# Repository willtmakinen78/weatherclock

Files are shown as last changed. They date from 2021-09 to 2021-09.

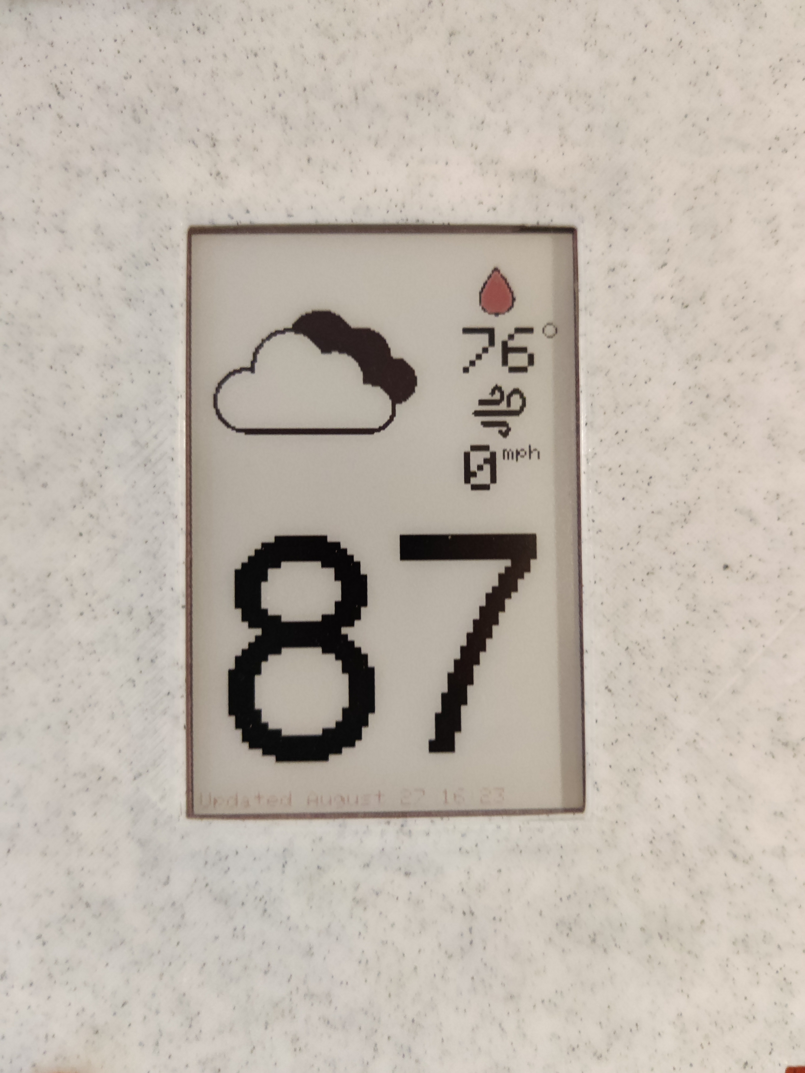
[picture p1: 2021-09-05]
pics/IMG_20210827_170801.jpg

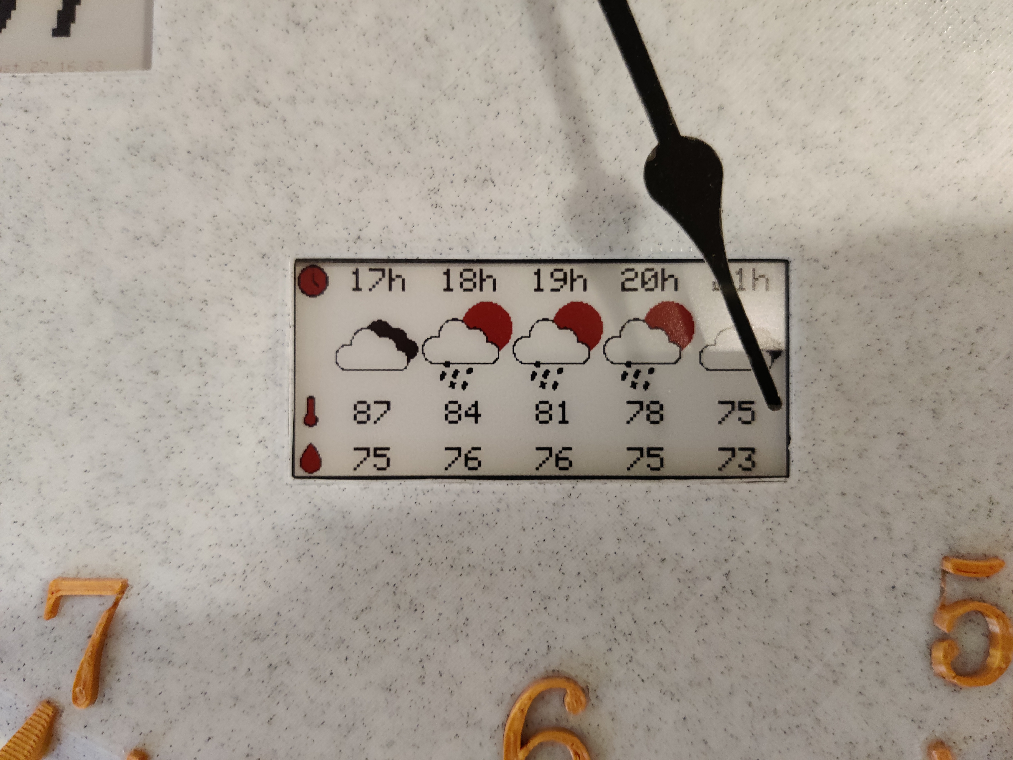
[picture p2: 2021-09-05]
pics/IMG_20210827_170815.jpg

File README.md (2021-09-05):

# weatherclock
An analog-digital hybrid wall clock that can tell the time and give a forecast for the current day.

This was one of my first forways into low power IOT electronics. At its core is an esp32, which is able to be placed into a deep sleep mode and absolutely sip power. Using two e-ink displays, the esp32 wakes up once an hour, grabs the current and hourly forecast from openweathermap.org, updates the displays, and then goes back to sleep. Due to to the fact that e-ink displays consume no power to hold an image on screen, power is only consumed during this update period once an hour, with the esp32 consuming microamps of current during sleep. This allows the clock to have a battery life of about one year, after which it can be charged through the integrated charing port.

Given the limited amount of display space available, the weather paremeters to display were chosen to reflect those most pertinent to running: temperature, dewpoint, and wind. Additionally, in the event of an SD card failure or low battery, one of the screens will be taken up by displaying an error icon notifying the user, as can be seen in the code.

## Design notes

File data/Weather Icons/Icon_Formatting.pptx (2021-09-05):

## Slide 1

11

11

11

11

11

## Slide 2

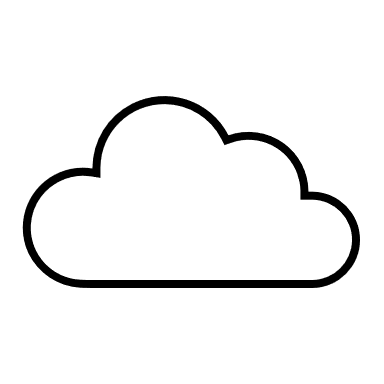
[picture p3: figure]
Cloud

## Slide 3

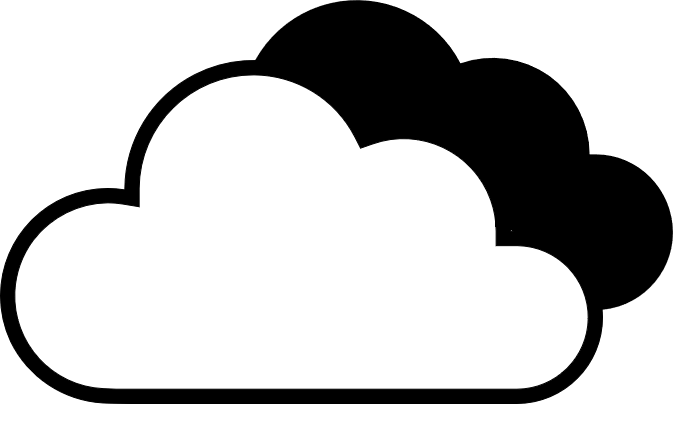
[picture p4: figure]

11

11

11

11

11

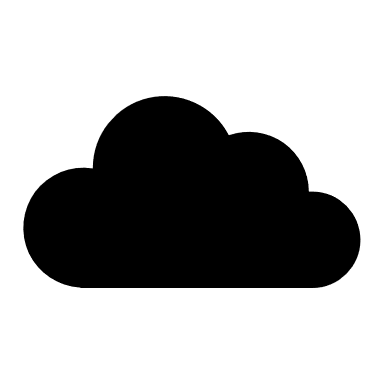
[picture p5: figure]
Cloud

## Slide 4

11

11

11

11

11

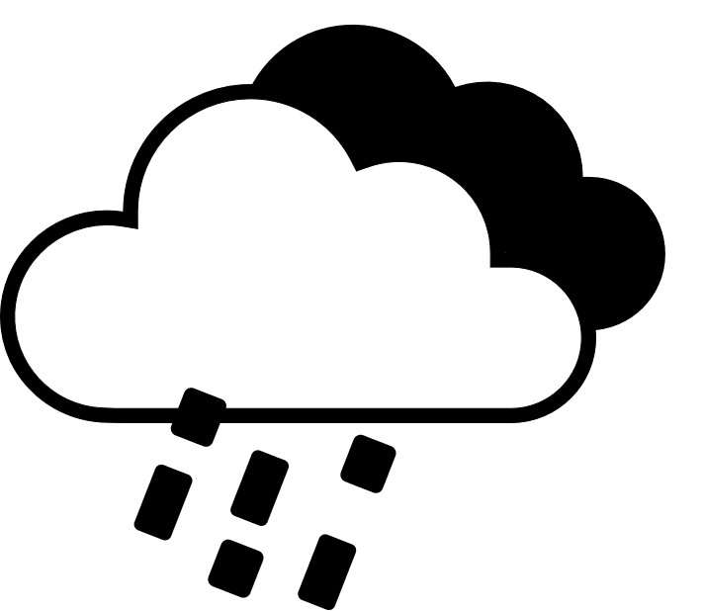
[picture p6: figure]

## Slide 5

11

11

11

11

11

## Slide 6

11

11

11

11

11

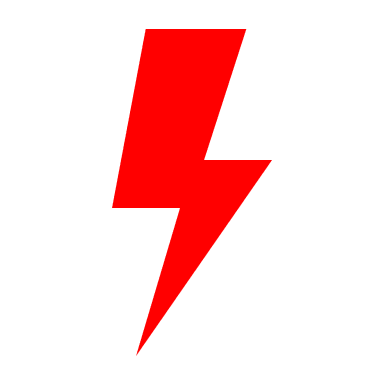
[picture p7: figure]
Lightning bolt
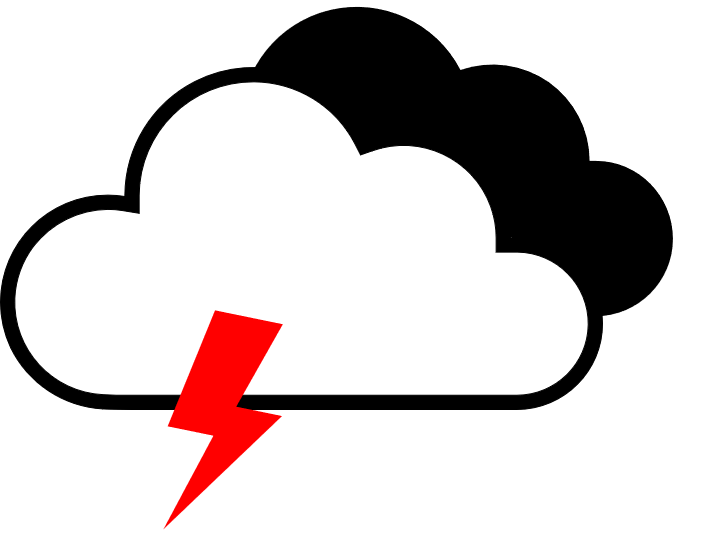
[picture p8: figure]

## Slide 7

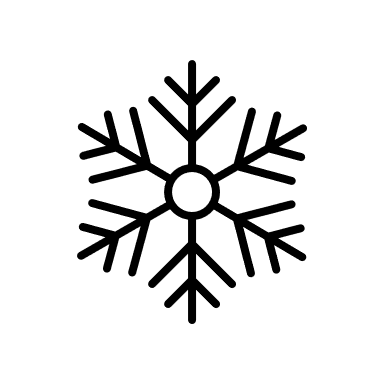
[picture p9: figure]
Snowflake
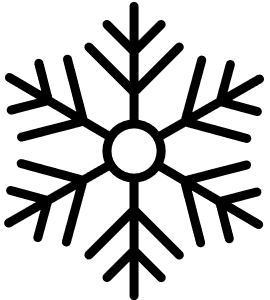
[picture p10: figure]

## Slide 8

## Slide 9

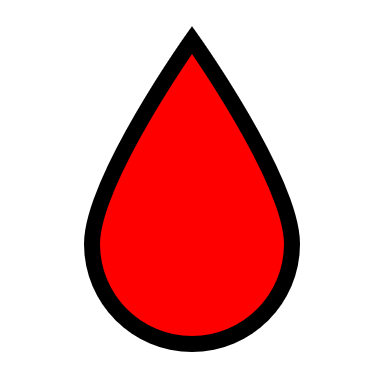
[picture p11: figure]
Water

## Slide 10

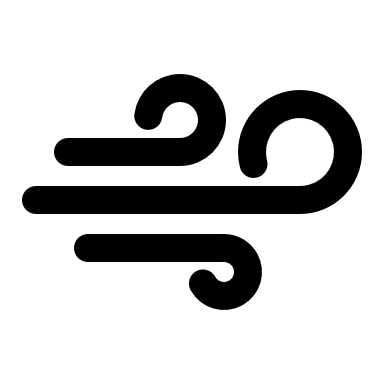
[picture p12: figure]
Windy
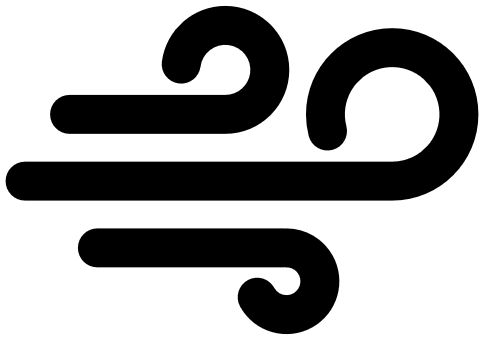
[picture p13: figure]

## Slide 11

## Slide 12

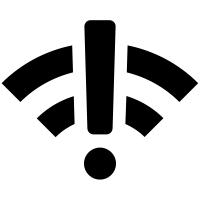
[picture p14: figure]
No Wifi Icons - Download Free Vector Icons | Noun Project
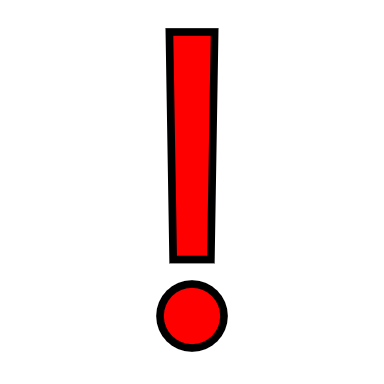
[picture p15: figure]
Exclamation mark
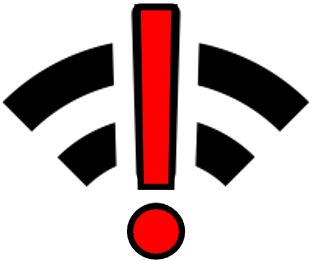
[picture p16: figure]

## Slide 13

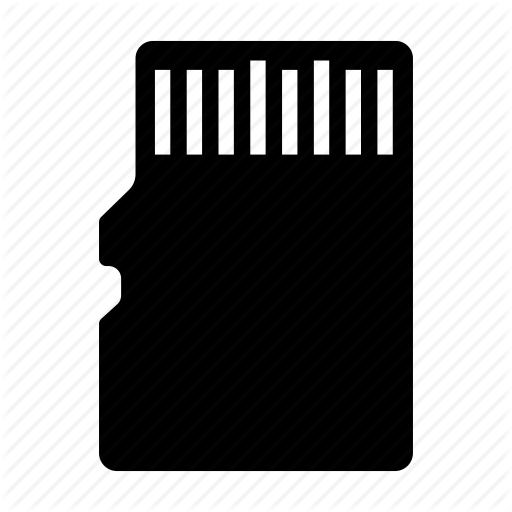
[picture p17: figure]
Data, flash memory, memory, memory card, micro sd, sd card icon
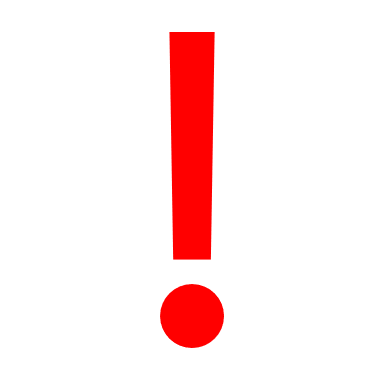
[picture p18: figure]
Exclamation mark
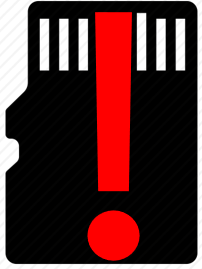
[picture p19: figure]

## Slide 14

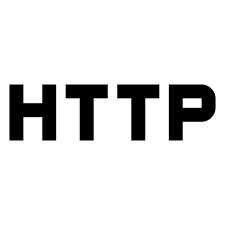
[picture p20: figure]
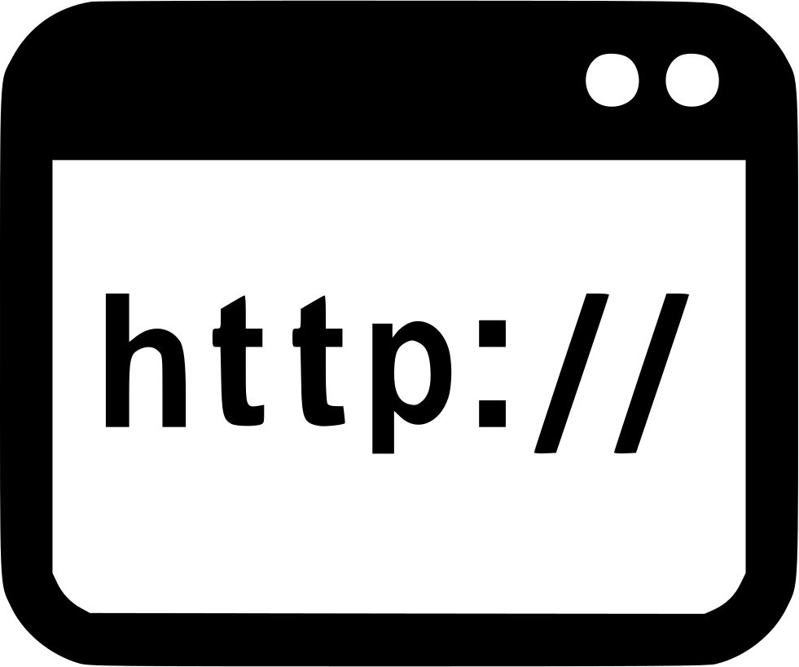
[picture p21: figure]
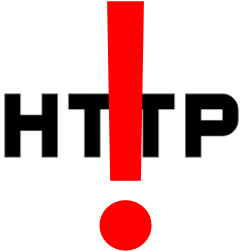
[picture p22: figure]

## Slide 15

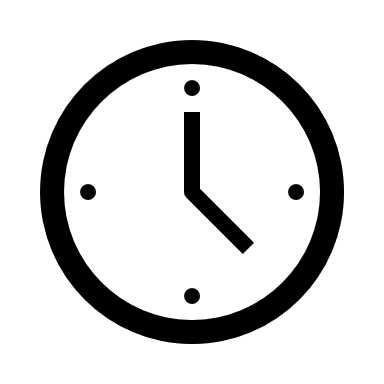
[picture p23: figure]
Clock
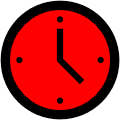
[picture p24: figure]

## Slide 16

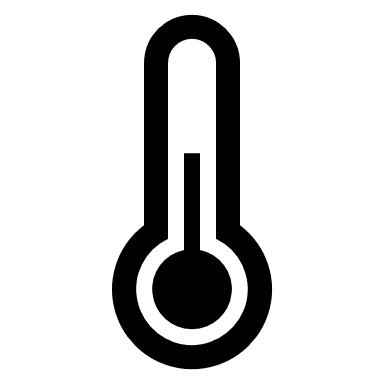
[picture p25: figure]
Thermometer

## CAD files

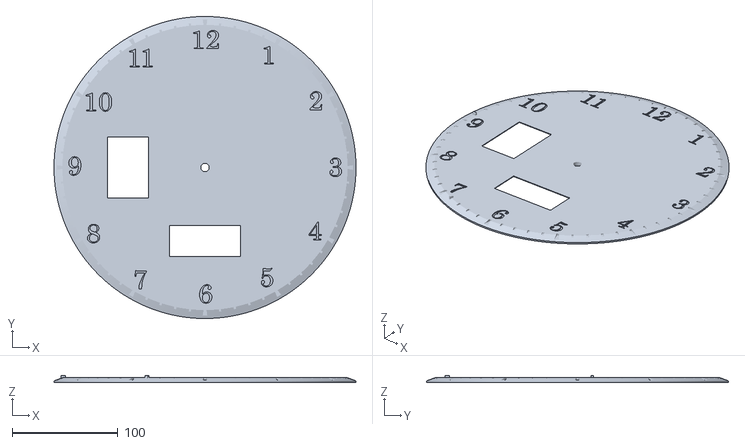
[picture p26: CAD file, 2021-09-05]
cad/Face/WeatherClock_Face.stl
285.0 x 285.0 x 6.50

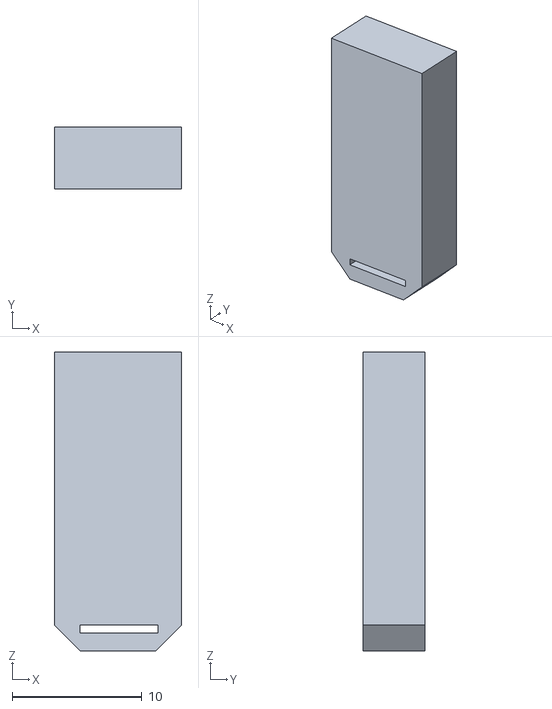
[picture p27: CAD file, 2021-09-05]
cad/Misc/WallMount.stl
9.80 x 4.80 x 23.0

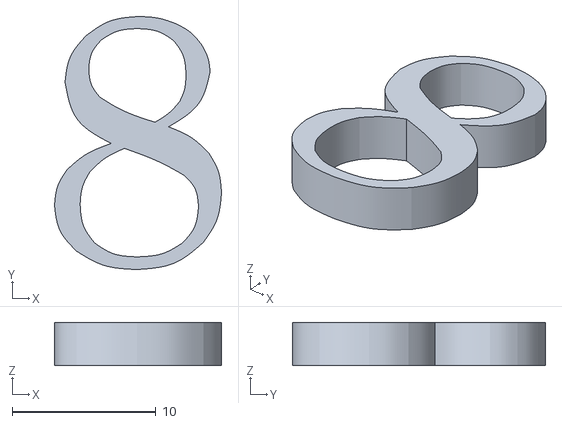
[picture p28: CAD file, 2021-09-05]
cad/Numbers/8.stl
11.6 x 17.6 x 3.00

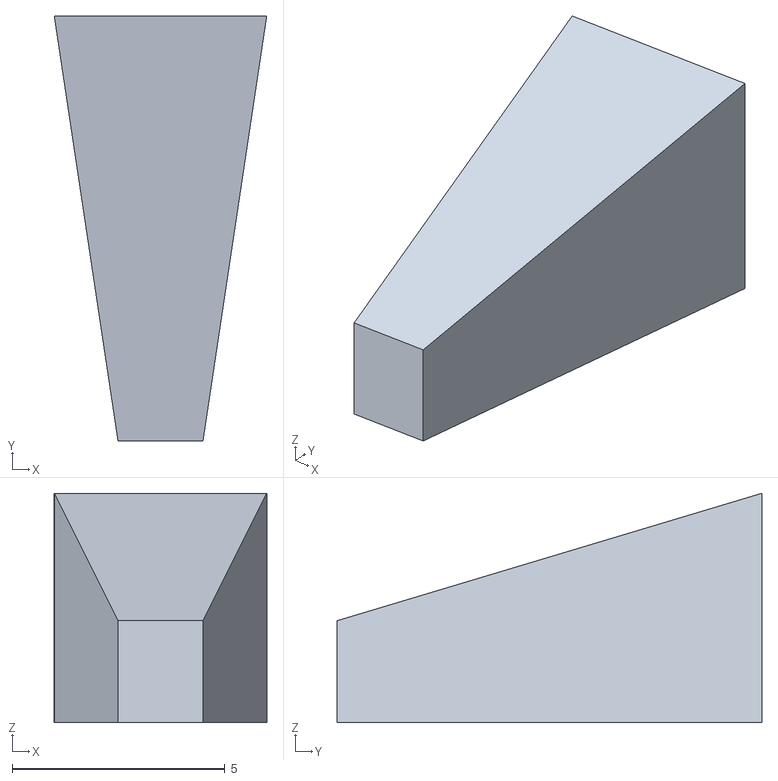
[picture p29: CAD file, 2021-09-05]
cad/Tiks/Tic.stl
5.00 x 10.0 x 5.40

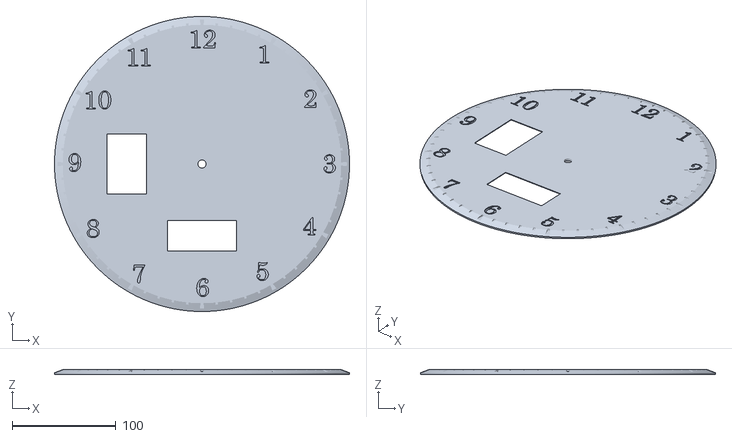
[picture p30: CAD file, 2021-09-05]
cad/Face/WeatherClock_Face_1.stl
285.0 x 285.0 x 4.50

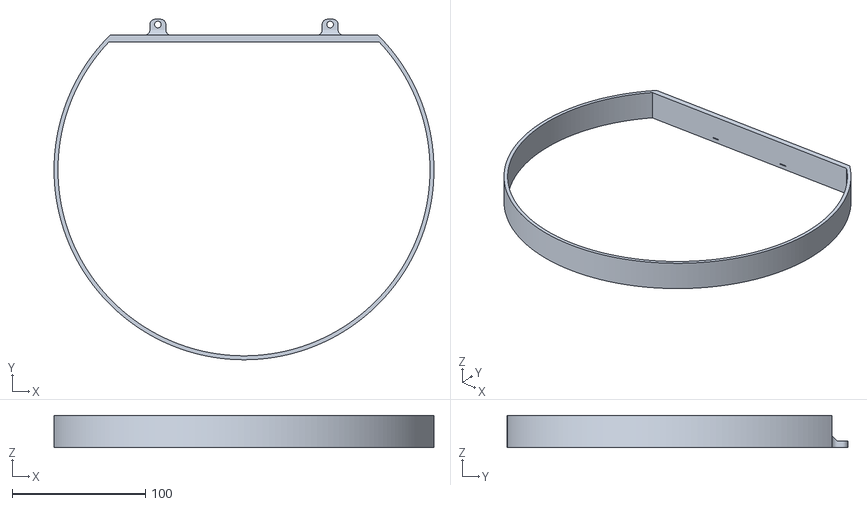
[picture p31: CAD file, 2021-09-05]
cad/Misc/Wall_Shroud.stl
285.0 x 255.4 x 24.0

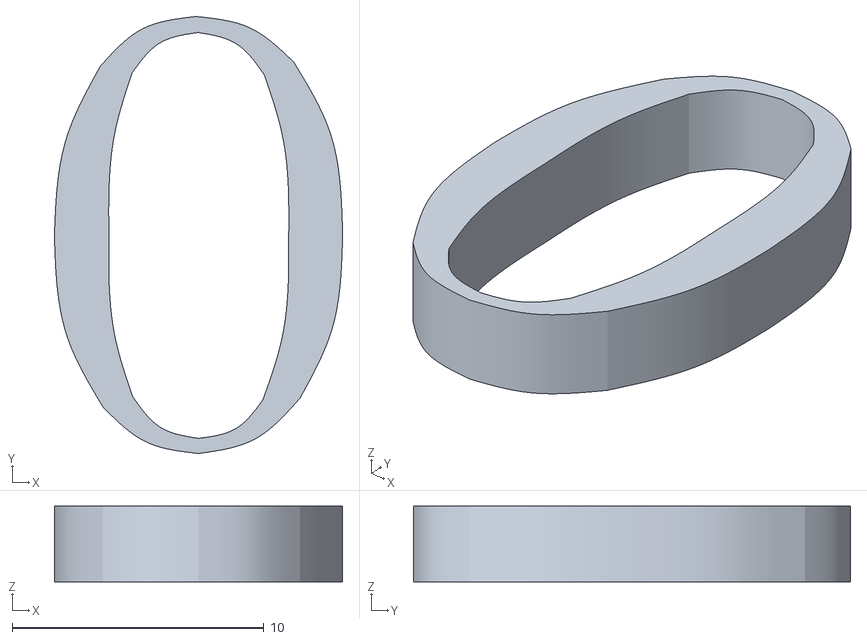
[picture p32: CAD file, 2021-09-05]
cad/Numbers/10_0.stl
11.4 x 17.3 x 3.00

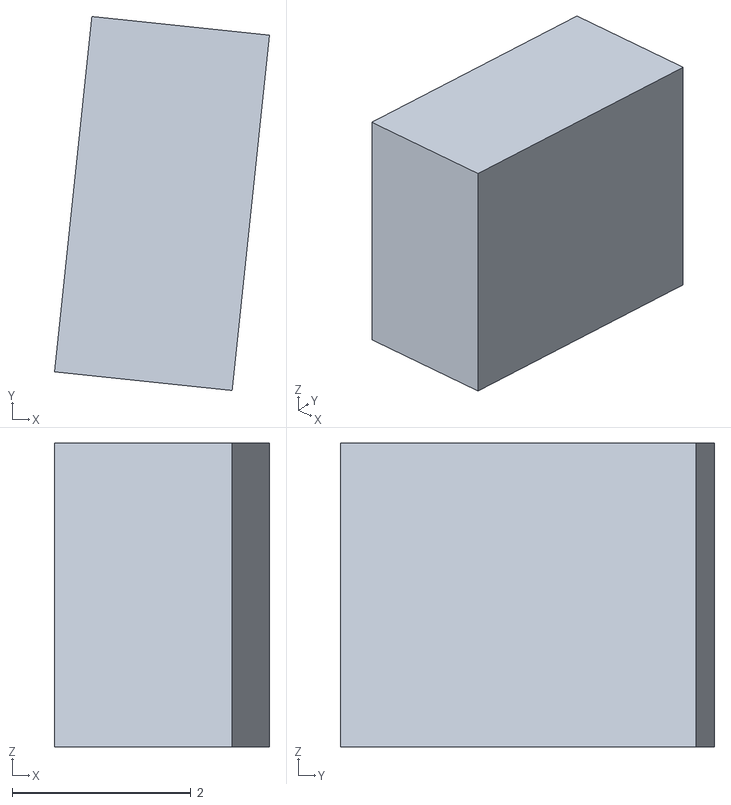
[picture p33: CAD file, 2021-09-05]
cad/Tiks/Toc.stl
2.41 x 4.19 x 3.40

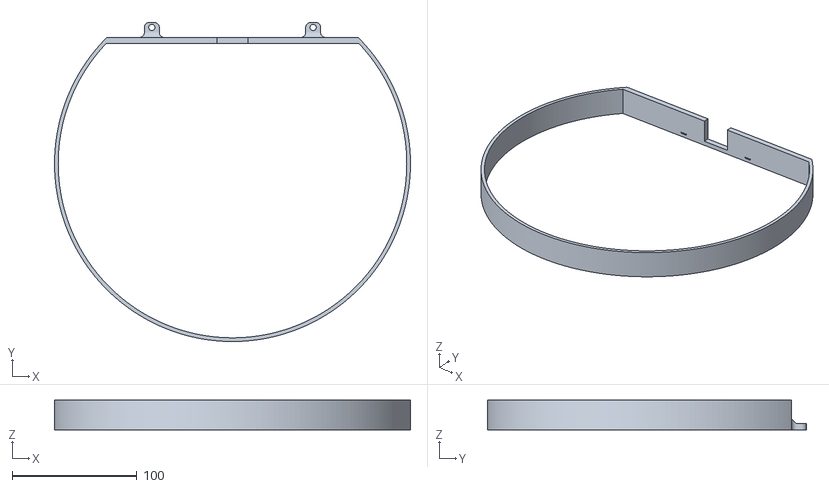
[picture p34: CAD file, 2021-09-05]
cad/Misc/Wall_Shroud_1.stl
285.0 x 255.4 x 24.0

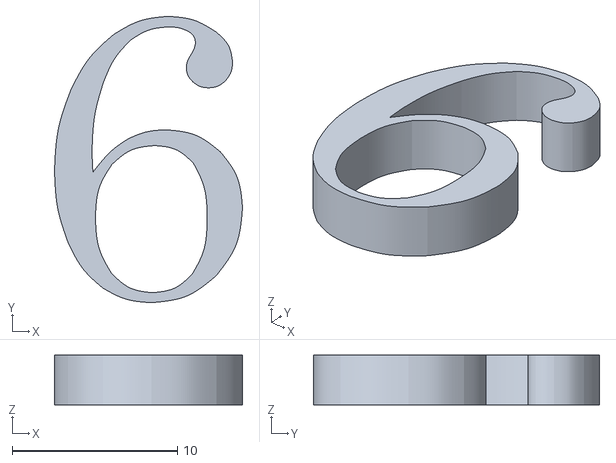
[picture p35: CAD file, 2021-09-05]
cad/Numbers/6.stl
11.4 x 17.3 x 3.00

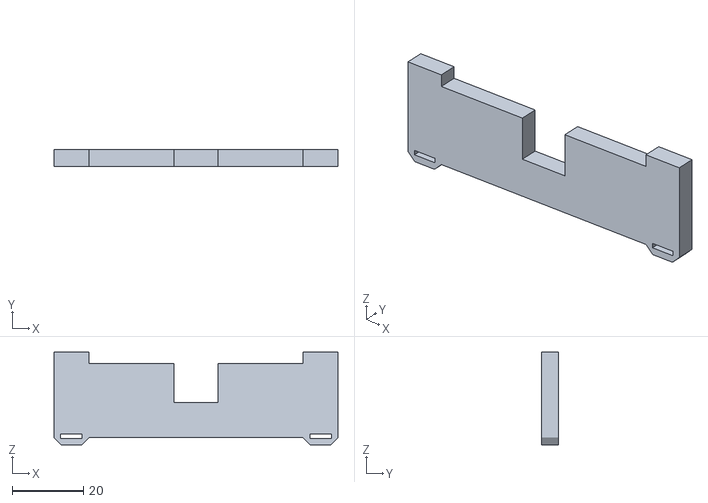
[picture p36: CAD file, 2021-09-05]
cad/Misc/WallMount_1.stl
79.8 x 4.80 x 26.0

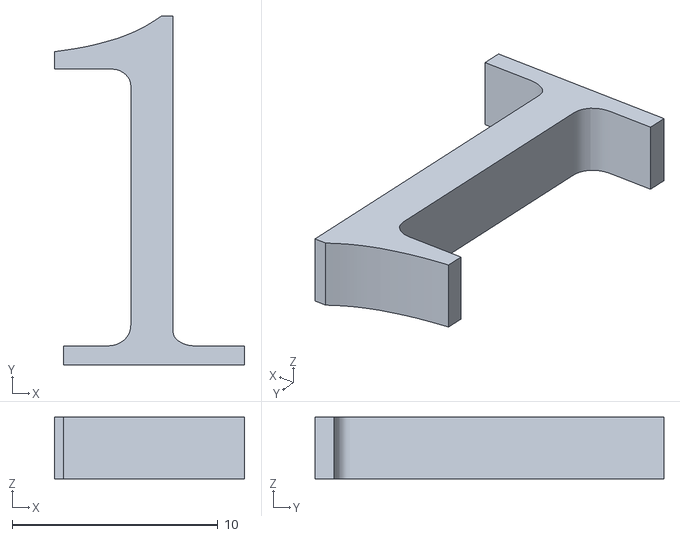
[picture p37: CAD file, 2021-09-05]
cad/Numbers/1.stl
9.23 x 16.9 x 3.00

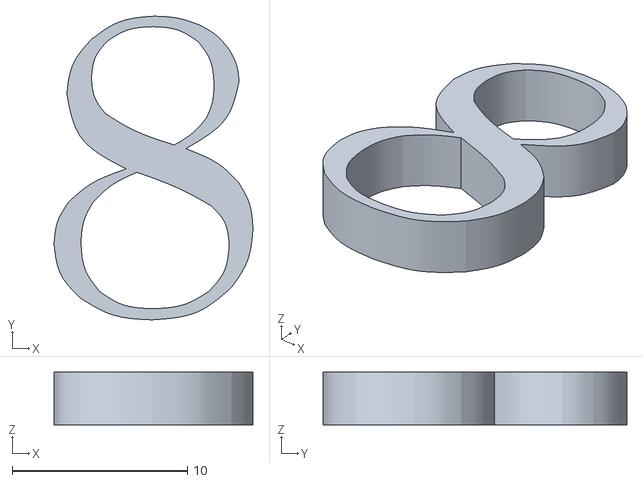
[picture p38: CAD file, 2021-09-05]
cad/Numbers/8_2.stl
11.4 x 17.4 x 3.00

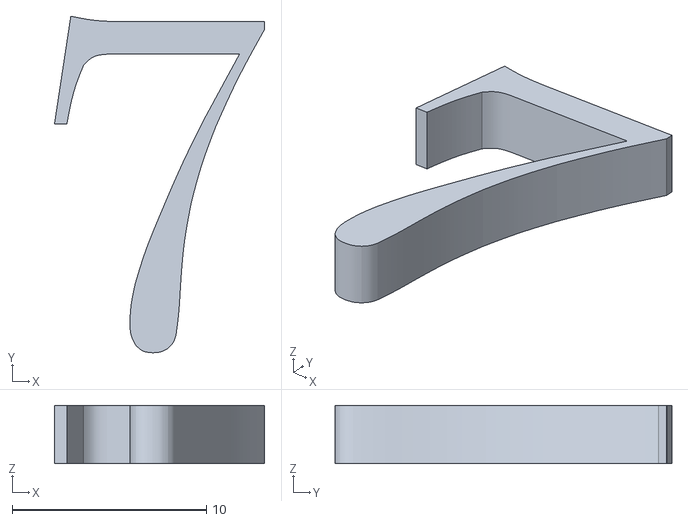
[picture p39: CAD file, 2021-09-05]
cad/Numbers/7.stl
10.8 x 17.3 x 3.00

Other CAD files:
cad/Hourly_Display_Layout.dwg
cad/Numbers/9.stl
cad/Numbers/1_1.stl
cad/Numbers/4.stl
cad/Numbers/1_2.stl
cad/Numbers/2.stl
cad/Numbers/3.stl
cad/Numbers/5.stl
cad/Numbers/8_1.stl

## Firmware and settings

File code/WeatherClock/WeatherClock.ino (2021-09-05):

/**************************************************************************/
/*
  library inclusions
*/

#include <Adafruit_GFX.h>
#include <HTTPClient.h>
#include <ArduinoJson.h>
#include <Adafruit_EPD.h>
#include <Adafruit_ImageReader_EPD.h>
#include <SdFat.h>
#include "info.h"
#include "time.h"
#include <Fonts/FreeSans24pt7b.h>

/**************************************************************************/
/*
  magic numbers
*/

// # of seconds to sleep between waking up and weather updates
#define SLEEP 3600

// WiFi timeout (seconds)
#define WIFI_TIMEOUT 45

// [temp, dewpoint, wind, iconId]
#define CURRENT_PARAMETER_NUM 4
#define NUM_HOURS 5
// [temp, dewpoint, iconId]
#define HOURLY_PARAMETER_NUM 3
#define TEMP_INDEX 0
#define DEWPOINT_INDEX 1
#define WIND_INDEX 2
#define CURRENT_ID 3
#define HOURLY_ID 2

// display dimensions
#define CURRENT_WIDTH 264
#define CURRENT_HEIGHT 176
#define HOURLY_WIDTH 296
#define HOURLY_HEIGHT 128

// ntp address
const char* ntpServer = "pool.ntp.org";

// how long to give the EPDs to flash the new image
#define DISPLAY_UPDATE_DELAY 7500

/**************************************************************************/
/*
  pin assignments
*/

// common to both displays
#define EPD_EN       22
#define EPD_RST      14

// current display
#define CURRENT_CS   32
#define CURRENT_DC   15
#define CURRENT_SRCS -1

// hourly display
#define HOURLY_CS    33
#define HOURLY_DC    27
#define HOURLY_SRCS  12
#define HOURLY_BUSY  -1

// use the SD card slot on the current display
#define SD_CS        23

// for battery monitoring
#define BAT_PIN A13
#define ADC_MAX 4095
#define VOLTAGE_SCALE 2
#define ESP32_VOLTAGE 3.3
#define REFERENCE_VOLTAGE 1.1
#define LOW_BATTERY 3.25

/**************************************************************************/
/*
  library initializations
*/

// 2.7" tricolor epd for current weather
Adafruit_IL91874 currentDisplay(CURRENT_WIDTH, CURRENT_HEIGHT, CURRENT_DC, EPD_RST, CURRENT_CS, CURRENT_SRCS);

// 2.9" tricolor epd for hourly forecast
Adafruit_IL0373 hourlyDisplay(HOURLY_WIDTH, HOURLY_HEIGHT, HOURLY_DC, EPD_RST, HOURLY_CS, HOURLY_SRCS, HOURLY_BUSY);

// SD card filesystem
SdFat SD;

// Image-reader object, pass in SD filesystem
Adafruit_ImageReader reader(SD);

/**************************************************************************/
/*
  due to sleeping, all the actual work will just be done in setup()
*/
void setup() 
{
  // start everything up
  initialize();

  // grab json string
  String jsonString = getJsonString(makeApiString());

  // error check for internet connectivity/http errors
  if (jsonString.length() < 1) {
    displayError('h');
  }

  // parse json for current weather and hourly forecast.
  // current weather order: [temp, dewpoint, wind, iconid]
  // hourly forecast: NUM_HOURS x HOURLY_PARAMETER_NUM array one entry
  // for each hour. order: [temp, dewpoint, icon]
  int currentWeather[CURRENT_PARAMETER_NUM];
  int hourlyWeather[NUM_HOURS][HOURLY_PARAMETER_NUM];
  parseJson(jsonString, currentWeather, hourlyWeather);

  Serial.print("Current Weather: ");
  for (int i = 0; i < CURRENT_PARAMETER_NUM; i++) {
    Serial.print(currentWeather[i]);
    Serial.print(", ");
  }
  Serial.println("\nHourly Forecast: ");
  for (int i = 0; i < NUM_HOURS; i++) {
    Serial.print("\thour "); Serial.print(i); Serial.print(": ");
    for (int j = 0; j < HOURLY_PARAMETER_NUM; j++) {
      Serial.print(hourlyWeather[i][j]);
      Serial.print(", ");
    }
    Serial.println();
  }

  // get current time before passing along`
  struct tm timeinfo = getTime();

  // set up before updating displays
  prepDisplays();

  // update current weather display
  updateCurrent(currentWeather, timeinfo);

  // update hourly forecast display
  updateHourly(hourlyWeather, timeinfo);

  Serial.println("drawing to displays");
  currentDisplay.display();
  hourlyDisplay.display();

  poweroff();
}
/**************************************************************************/
/*
  initialize all libraries and components
*/
void initialize()
{
  Serial.begin(9600);

  // enable the display's regulators
  pinMode(EPD_EN, OUTPUT);
  digitalWrite(EPD_EN, HIGH);
  Serial.println("displays enabled");

  // initialize both displays and clear their buffers
  currentDisplay.begin();
  hourlyDisplay.begin();
  Serial.println("displays initialized");

  // initialize sd card
  if (!SD.begin(SD_CS, SD_SCK_MHZ(10))) {
    displayError('s');
  }
  Serial.println("SD card initialized");

  // check for low battery
  float voltage = float(analogRead(BAT_PIN)) / float(ADC_MAX) *
                  VOLTAGE_SCALE * ESP32_VOLTAGE * REFERENCE_VOLTAGE;
  Serial.print("lipo voltage: ");
  Serial.println(voltage);
  if (voltage <= LOW_BATTERY) {
    displayError('b');
  }
  else {
    Serial.println("battery ok");
  }

  // initialize wifi
  Serial.print("Connecting to WiFi ");
  WiFi.begin(WIFI_SSID, WIFI_PASSWORD);
  int counter = 0;
  while (WiFi.status() != WL_CONNECTED && counter < WIFI_TIMEOUT) {
    delay(1000);
    Serial.print(".");
    counter++;
  }
  if (WiFi.status() == WL_CONNECTED) {
    Serial.println("connected");
  }
  else {
    displayError('w');
  }

}
/**************************************************************************/
/*
  put everything into low-power mode then sleep
*/
void poweroff()
{
  Serial.println("powering down");
  currentDisplay.powerDown();
  hourlyDisplay.powerDown();
  Serial.println("sleeping");
  ESP.deepSleep(SLEEP * 1e6);
}
/**************************************************************************/
/*
  get current time
*/
struct tm getTime() {
  Serial.println("getting time from NTP");
  configTime(GMTOFFSET_SEC, DAYLIGHTOFFSET_SEC, ntpServer);
  struct tm timeinfo;
  if (!getLocalTime(&timeinfo)) {
    Serial.println("Failed to obtain update time");
  }
  else {
    Serial.println("NTP update successful");
  }

  return timeinfo;
}

/**************************************************************************/

void loop() {
  // will never reach this point; included for completion
}

/**************************************************************************/

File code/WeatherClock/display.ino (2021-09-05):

/**************************************************************************/
/*
  library inclusions
*/
/**************************************************************************/
/*
  magic numbers
*/

// icon ids
#define DEWPOINT_ID 20
#define WIND_ID     21
#define BATTERY_ID  30
#define WIFI_ID     31
#define SD_ID       32
#define HTTP_ID     33
#define CLOCK_ID    40
#define TEMP_ID     41

#define HOURLY_ICON_SIZE  55
#define ERROR_ICON_SIZE   100

const GFXfont *tempFont = &FreeSans24pt7b;

/**************************************************************************/
/*
  get displays ready to and set general formatting parameters
*/
void prepDisplays() {
  currentDisplay.clearBuffer();
  hourlyDisplay.clearBuffer();

  currentDisplay.setRotation(3);
  currentDisplay.fillScreen(EPD_WHITE);
  currentDisplay.setTextWrap(false);

  hourlyDisplay.fillScreen(EPD_WHITE);
  hourlyDisplay.setTextWrap(false);
}
/**************************************************************************/
/*
  display current weather info on currentDisplay. timeinfo prints update time
  order: [temp, dewpoint, wind, iconid]
*/
void updateCurrent(int currentWeather[CURRENT_PARAMETER_NUM], struct tm timeinfo)
{
  int temp = currentWeather[TEMP_INDEX];
  int dewpoint = currentWeather[DEWPOINT_INDEX];
  int wind = currentWeather[WIND_INDEX];
  int iconId = currentWeather[CURRENT_ID];

  // big temp text
  currentDisplay.setTextColor(EPD_BLACK);
  currentDisplay.setCursor(10, currentDisplay.height() - 35);
  currentDisplay.setFont(tempFont);
  currentDisplay.setTextSize(3);
  currentDisplay.println(temp);

  // icon
  displayIcon(iconId, 5, 15, 'l');
  //  currentDisplay.drawRect(5, 15, 100, 100, EPD_RED);

  // dewpoint
  // dewpoint icon
  displayIcon(DEWPOINT_ID, currentDisplay.width() - 48, 15, 'a');
  // text
  currentDisplay.setTextColor(EPD_BLACK);
  currentDisplay.setCursor(currentDisplay.width() - 52, 50);
  currentDisplay.setFont(NULL);
  currentDisplay.setTextSize(3);
  currentDisplay.println(dewpoint);
  // degree symbol
  currentDisplay.drawCircle(currentDisplay.width() - 12, 45, 3, EPD_BLACK);

  // windspeed
  // wind icon
  displayIcon(WIND_ID, currentDisplay.width() - 48, 70, 'a');
  // number text
  currentDisplay.setTextColor(EPD_BLACK);
  currentDisplay.setCursor(currentDisplay.width() - 52, 98);
  currentDisplay.setFont(NULL);
  currentDisplay.setTextSize(3);
  currentDisplay.print(wind);
  // mph text
  currentDisplay.setTextSize(0);
  currentDisplay.println("mph");

  // update time
  //  printUpdateTime();
  currentDisplay.setTextColor(EPD_RED);
  currentDisplay.setCursor(3, currentDisplay.height() - 10);
  currentDisplay.setFont(NULL);
  currentDisplay.setTextSize(0);
  currentDisplay.print("Updated ");
  currentDisplay.print(&timeinfo, "%B %d %H:%M");
}
/**************************************************************************/
/*
  display hourly forecast on hourlyDisplay using input array hourlyWeather
*/
void updateHourly(int hourlyWeather[NUM_HOURS][HOURLY_PARAMETER_NUM], struct tm timeinfo)
{
  int h = timeinfo.tm_hour;

  // draw key icons
  displayIcon(CLOCK_ID, 1, 1, 's');
  displayIcon(TEMP_ID, 0, 80, 's');
  displayIcon(DEWPOINT_ID, 0, 107, 's');

  hourlyDisplay.setTextColor(EPD_BLACK);
  hourlyDisplay.setFont(NULL);
  hourlyDisplay.setTextSize(2);

  for (int i = 0; i < NUM_HOURS; i++) {
    int hPrint = h + i + 1;
    if (hPrint > 23) hPrint = i;

    // times
    hourlyDisplay.setCursor(i * HOURLY_ICON_SIZE + 32, 3);
    hourlyDisplay.printf("%02dh", hPrint);

    // weather icons
    displayIcon(hourlyWeather[i][HOURLY_ID], i * HOURLY_ICON_SIZE + 21, 23, 's');
   
    // temps
    hourlyDisplay.setCursor(i * HOURLY_ICON_SIZE + 35, 83);
    hourlyDisplay.print(hourlyWeather[i][TEMP_INDEX]);

    // dewpoints
    hourlyDisplay.setCursor(i * HOURLY_ICON_SIZE + 35, 111);
    hourlyDisplay.print(hourlyWeather[i][DEWPOINT_INDEX]);
  }
}
/**************************************************************************/
/*
  display iconid at x, y, loading differently depending on type
*/
void displayIcon(int iconId, int x, int y, char type)
{
  String id = String(iconId);
  // the image to load into RAM
  Adafruit_Image_EPD img;

  switch (type)
  {
    // auxillary icon for current display
    case 'a': {
        Serial.print("updating auxillary icon. SD read status: ");

        String path = "/auxillary/" + id + ".bmp";
        int len = path.length();
        char buf[len + 1];
        path.toCharArray(buf, len + 1);

        ImageReturnCode stat = reader.loadBMP(buf, img);
        reader.printStatus(stat);

        img.draw(currentDisplay, x, y);
      }
      break;
    // large icon for current display
    case 'l':
      {
        Serial.print("updating large icon. SD read status: ");

        String path = "/large/" + id + ".bmp";
        int len = path.length();
        char buf[len + 1];
        path.toCharArray(buf, len + 1);

        ImageReturnCode stat = reader.loadBMP(buf, img);
        reader.printStatus(stat);

        img.draw(currentDisplay, x, y);
      }
      break;
    // small icon for hourly display
    case 's':
      {
        Serial.print("updating small icon. SD read status: ");

        String path = "/small/" + id + ".bmp";
        int len = path.length();
        char buf[len + 1];
        path.toCharArray(buf, len + 1);

        ImageReturnCode stat = reader.loadBMP(buf, img);
        reader.printStatus(stat);

        img.draw(hourlyDisplay, x, y);
      }
      break;
    // error icon for hourly display
    case 'e':
      {
        Serial.print("updating error icon. SD read status: ");

        String path = "/error/" + id + ".bmp";
        int len = path.length();
        char buf[len + 1];
        path.toCharArray(buf, len + 1);

        ImageReturnCode stat = reader.loadBMP(buf, img);
        reader.printStatus(stat);

        img.draw(hourlyDisplay, x, y);
      }
      break;
  }
}
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
